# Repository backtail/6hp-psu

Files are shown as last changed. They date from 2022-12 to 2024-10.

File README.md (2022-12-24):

# 6hp psu
6HP Eurorack module

### Render
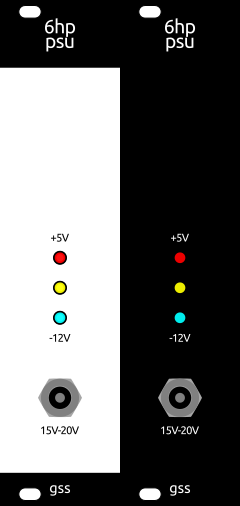
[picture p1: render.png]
 

### Input
- 15V-20V
- 2.1/5.5mm Barrel Jack 
- use a *USB PD Trigger Adapter* i.e. to use a power bank

### Output
Without a heatsink
* +5V @ 1.5A
* +12V @ 1A
* -12V @ 1A

Not tested with a heatsink yet. Potentially up to 2..2.5A
per rail! *(Depending on heatsink dimensions and rack depth)*

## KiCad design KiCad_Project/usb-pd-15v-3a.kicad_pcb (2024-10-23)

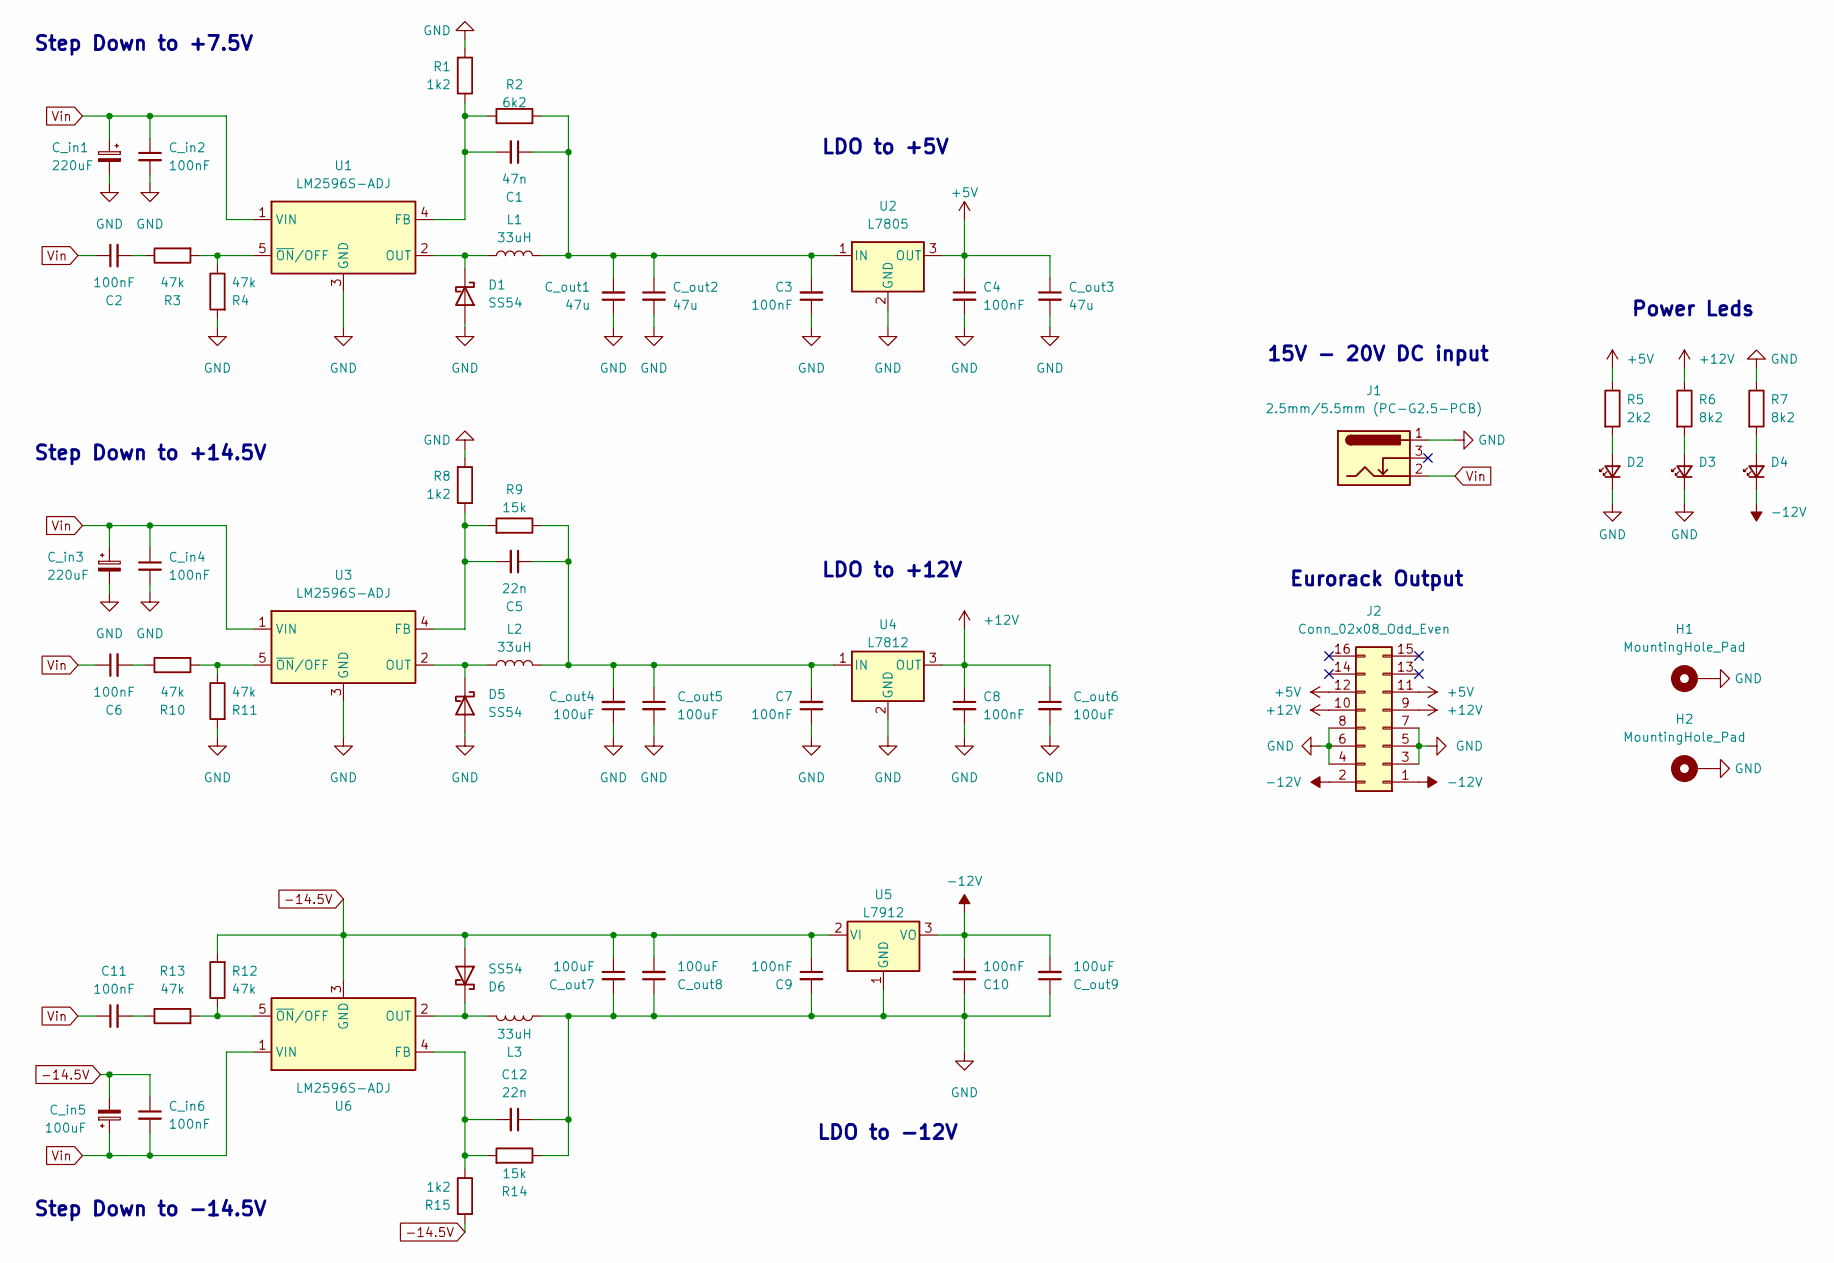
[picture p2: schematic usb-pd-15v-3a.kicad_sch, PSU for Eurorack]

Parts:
C1: 47n; C_0603_1608Metric; JLCPCB Reference C1622
C2, C3, C4, C6, C7, C8, C9, C10, C11: 100nF; C_0805_2012Metric; JLCPCB Reference C49678
C5, C12: 22n; C_0603_1608Metric; JLCPCB Reference C21122
C_in1, C_in3: 220uF; CP_Elec_10x7.7; JLCPCB Reference C249881
C_in2, C_in4, C_in6: 100nF; C_1206_3216Metric; JLCPCB Reference C24497
C_in5: 100uF; CP_Elec_6.3x7.7; JLCPCB Reference C165974
C_out1, C_out2, C_out3: 47u; C_1206_3216Metric; JLCPCB Reference C96123
C_out4, C_out5, C_out6, C_out7, C_out8, C_out9: 100uF; L_1210_3225Metric; JLCPCB Reference C90143
D1, D5, D6: SS54; D_SMA; JLCPCB Reference C22452
D2, D3, D4: LED_D3.0mm
H1, H2: MountingHole_Pad; MountingHole_3.2mm_M3_Pad_TopOnly
J1: 2.5mm/5.5mm (PC-G2.5-PCB); DC_Barrel_Jack_2.5mm_5.7mm_Verrtical
J2: Conn_02x08_Odd_Even; IDC-Header_2x08_P2.54mm_Vertical
L1, L2, L3: 33uH; L_12x12mm_H8mm; JLCPCB Reference C718306
R1, R8, R15: 1k2; R_0805_2012Metric_Pad1.20x1.40mm_HandSolder; JLCPCB Reference C17379
R2: 6k2; R_0805_2012Metric_Pad1.20x1.40mm_HandSolder; JLCPCB Reference C17767
R3, R4, R10, R11, R12, R13: 47k; R_0603_1608Metric; JLCPCB Reference C25819
R5: 2k2; R_0603_1608Metric; JLCPCB Reference C4190
R6, R7: 8k2; R_0603_1608Metric; JLCPCB Reference C25981
R9, R14: 15k; R_0805_2012Metric_Pad1.20x1.40mm_HandSolder; JLCPCB Reference C17475
U1, U3, U6: LM2596S-ADJ; TO-263-5_TabPin3; JLCPCB Reference C347423
U2: L7805; TO-263-3_TabPin2; JLCPCB Reference C507146
U4: L7812; TO-263-3_TabPin2; JLCPCB Reference C507140
U5: L7912; TO-263-3_TabPin2; JLCPCB Reference C2926383

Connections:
+5V: C4.1, C_out3.1, J2.11, J2.12, R5.1, U2.3 (OUT)
+12V: C8.1, C_out6.1, J2.9, J2.10, R6.1, U4.3 (OUT)
-12V: C10.2, C_out9.2, D4.1 (K), J2.1, J2.2, U5.3 (VO)
-14.5V: C9.1, C_in5.2, C_in6.1, C_out7.1, C_out8.2, D6.2 (A), R12.2, R15.2, U5.2 (VI), U6.3 (GND)
GND: C3.1, C4.2, C7.1, C8.2, C9.2, C10.1, C12.1, C_in1.2, C_in2.2, C_in3.2, C_in4.2, C_out1.1, C_out2.2, C_out3.2, C_out4.1, C_out5.2, C_out6.2, C_out7.2, C_out8.1, C_out9.1, D1.2 (A), D2.1 (K), D3.1 (K), D5.2 (A), H1.1, H2.1, J1.1, J2.3, J2.4, J2.5, J2.6, J2.7, J2.8, L3.1, R1.2, R4.2, R7.1, R8.2, R11.2, R14.1, U1.3 (GND), U2.2 (GND), U3.3 (GND), U4.2 (GND), U5.1 (GND)
unnamed: C1.1, C3.2, C_out1.2, C_out2.1, L1.2, R2.2, U2.1 (IN)
unnamed: C1.2, R1.1, R2.1, U1.4 (FB)
unnamed: C2.2, R3.1
unnamed: C5.1, C7.2, C_out4.2, C_out5.1, L2.2, R9.1, U4.1 (IN)
unnamed: C5.2, R8.1, R9.2, U3.4 (FB)
unnamed: C6.2, R10.1
unnamed: C11.2, R13.1
unnamed: C12.2, R14.2, R15.1, U6.4 (FB)
unnamed: D1.1 (K), L1.1, U1.2 (OUT)
unnamed: D2.2 (A), R5.2
unnamed: D3.2 (A), R6.2
unnamed: D4.2 (A), R7.2
unnamed: D5.1 (K), L2.1, U3.2 (OUT)
unnamed: D6.1 (K), L3.2, U6.2 (OUT)
unnamed: R3.2, R4.1, U1.5 (~ON/OFF)
unnamed: R10.2, R11.1, U3.5 (~ON/OFF)
unnamed: R12.1, R13.2, U6.5 (~ON/OFF)
Vin: C2.1, C6.1, C11.1, C_in1.1, C_in2.1, C_in3.1, C_in4.1, C_in5.1, C_in6.2, J1.2, U1.1 (VIN), U3.1 (VIN), U6.1 (VIN)

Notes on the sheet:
LDO to -12V
LDO to +12V
Eurorack Output
Power Leds
Step Down to +14.5V
15V - 20V DC input
Step Down to +7.5V
Step Down to -14.5V
LDO to +5V

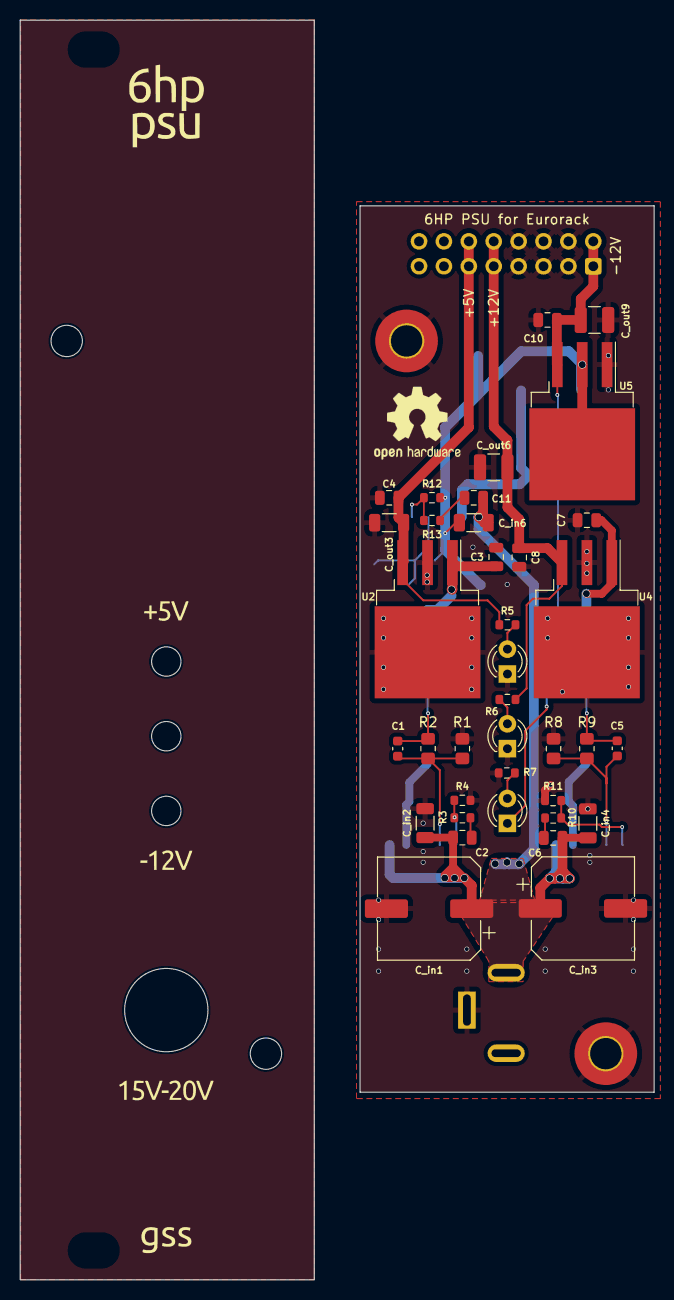
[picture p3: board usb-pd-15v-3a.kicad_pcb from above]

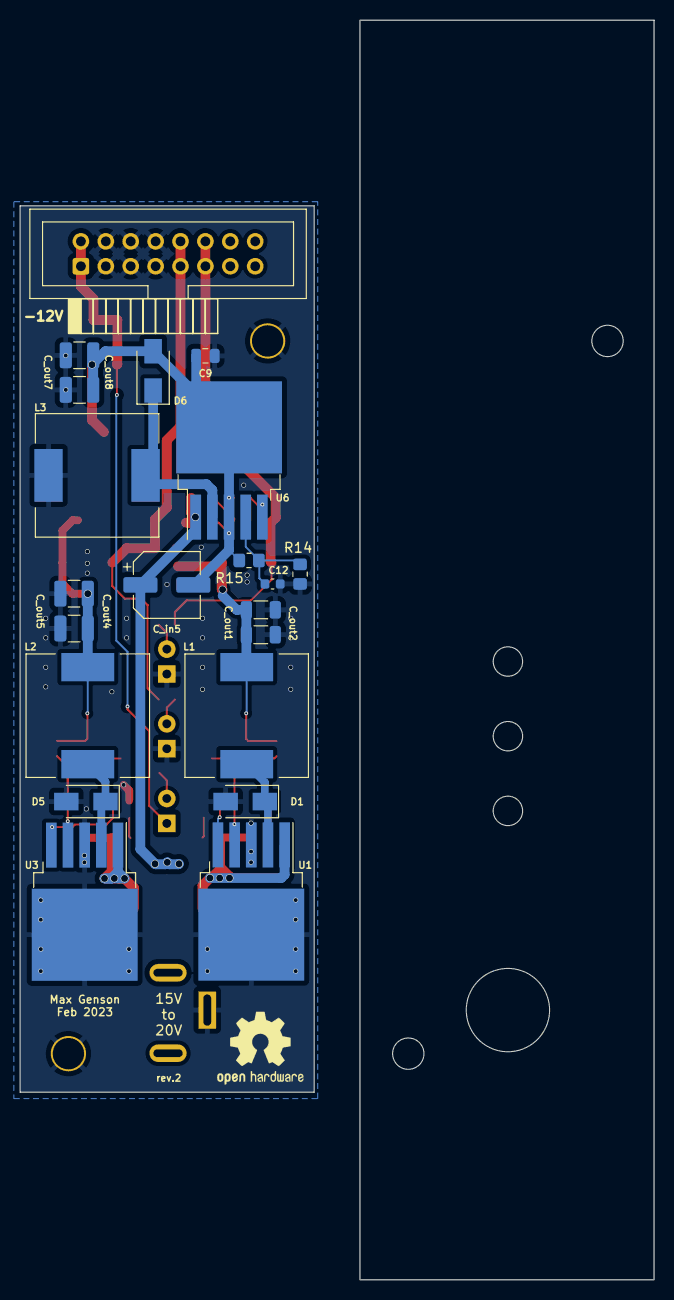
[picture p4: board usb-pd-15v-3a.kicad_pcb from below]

Board: 4 copper layers, 30.0 x 90.4 mm, 61 parts (21 on the bottom side), 23 nets.
